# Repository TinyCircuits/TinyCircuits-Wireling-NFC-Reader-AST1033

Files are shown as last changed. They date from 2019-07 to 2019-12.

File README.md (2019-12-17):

# TinyCircuits Wireling NFC Reader
# AST1033 Rev1

The design files are located under design_files/ for the TinyCircuits AST1033 Rev 1 PCB. This is a Wireling board which features the MFRC522 RFID Reader and is designed to communicate with ISO/IEC 14443 A/MIFARE cards and transponders.

Format is in Cadsoft Eagle format - Eagle version 6.2 was used for the original design.

For more infomation on this, check out the product page at TinyCircuits.com

# License:

Design by TinyCircuits.
All design files are released under the Creative Commons Attribution Share-Alike 3.0 License, see the following link for details: http://creativecommons.org/licenses/by-sa/3.0

All text above must be included in any redistribution or derived design

This project uses designs and concepts developed as part of the Arduino project and the LilyPad project.  The TinyCircuits design files themselves (schematics, PCB and libraries) are not directly derived from these works' design files and have been created new, however the concepts and basic architecture behind the TinyDuino and TinyLily products are derived and we thank the hard work of the organizations below for their contributions to open-source hardware:
  
Original Arduino Uno Design by Team Arduino

LilyPad Arduino Design by Leah Buechley and Sparkfun Electronics

Please support the open-source hardware community

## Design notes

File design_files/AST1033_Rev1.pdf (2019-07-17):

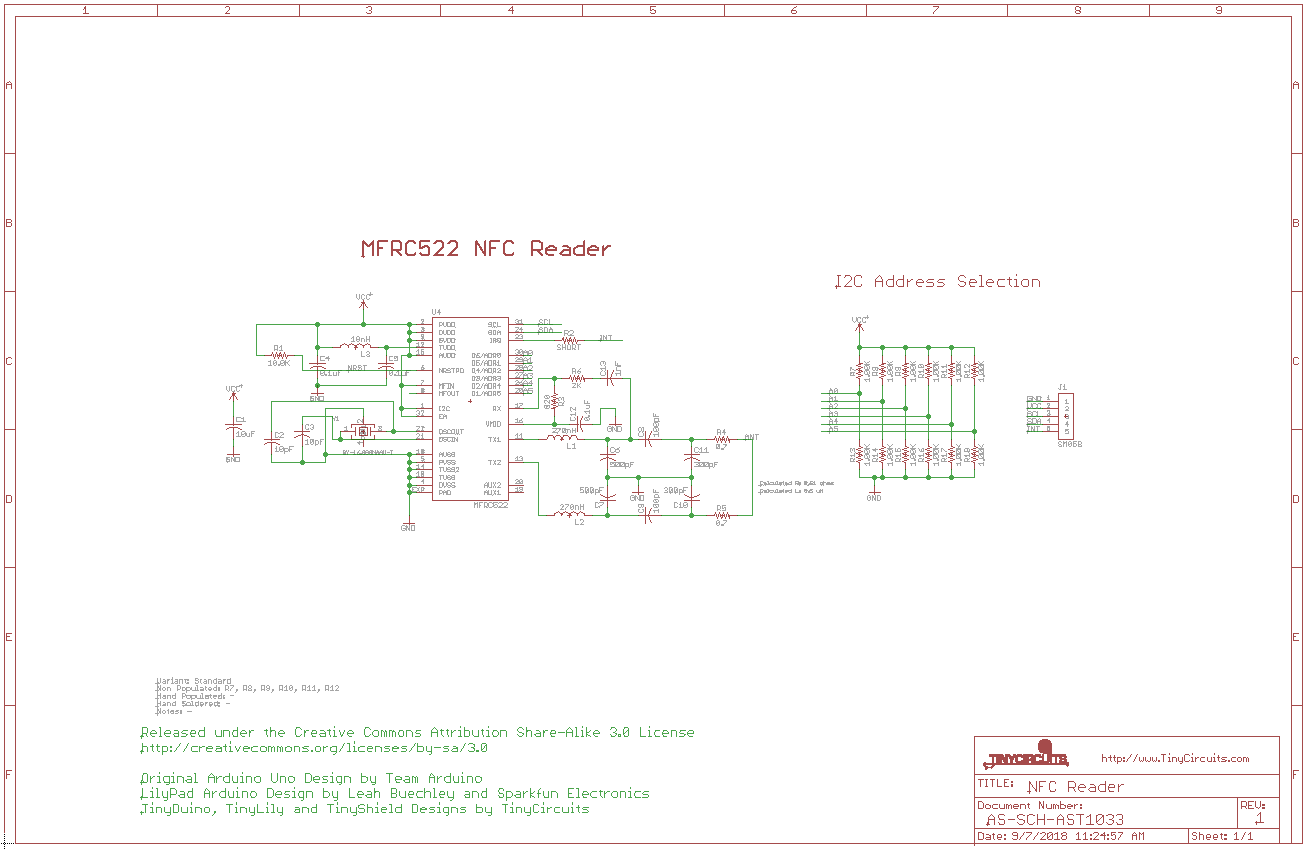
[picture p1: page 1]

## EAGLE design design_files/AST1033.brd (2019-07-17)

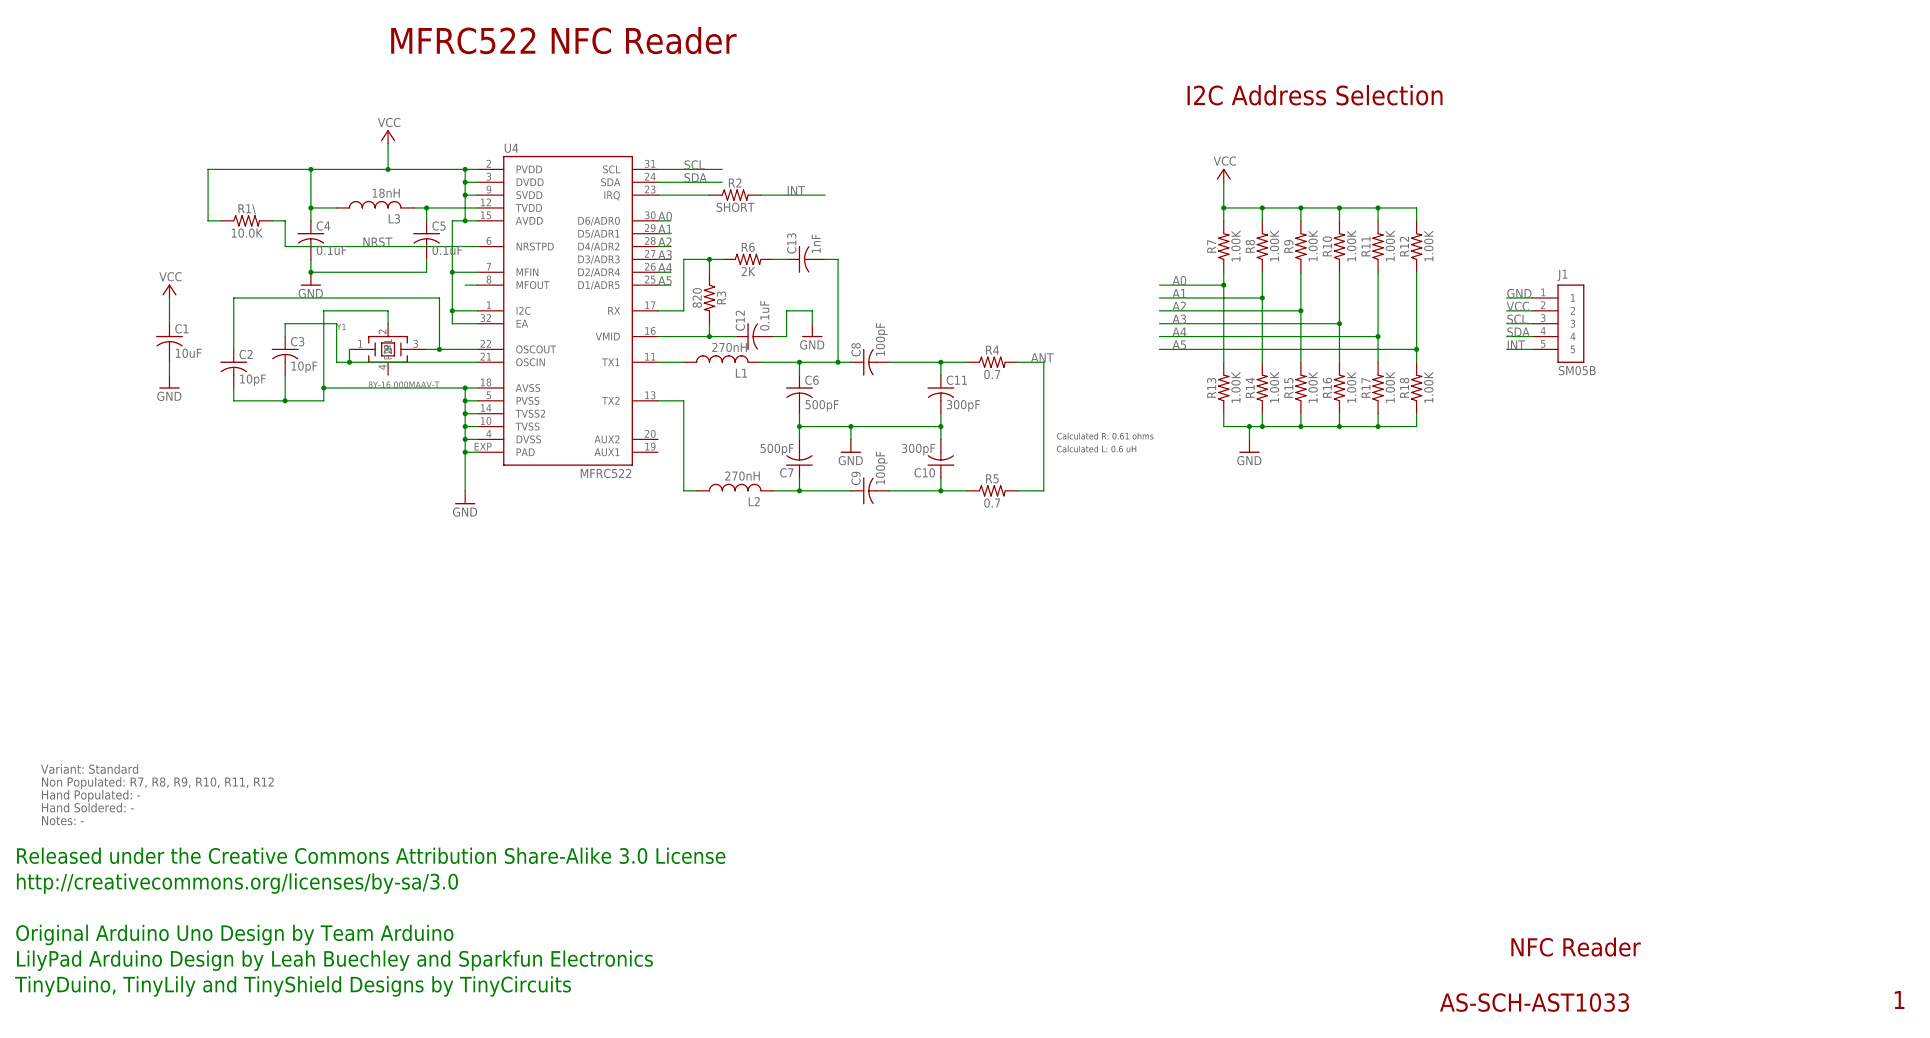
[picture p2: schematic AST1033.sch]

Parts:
C1: 10uF; C0603; PARTNO AS-ITM-00002
C2, C3: 10pF; C0402
C4, C5, C12: 0.1uF; C0402; PARTNO AS-ITM-00008
C6, C7: 500pF; 0402; PARTNO AS-ITM-00148
C8, C9: 100pF; 0402; PARTNO AS-ITM-00148
C10, C11: 300pF; C0402; PARTNO AS-ITM-00008
C13: 1nF; C0402; PARTNO AS-ITM-00008
J1: SM05B; JST_SH_5X1
L1, L2: 270nH; C0402; PARTNO AS-ITM-00250
L3: 18nH; C0402
R1\: 10.0K; 0402
R2: SHORT; 0402_SHORT
R3: 820; 0402; PARTNO AS-ITM-00076
R4, R5: 0.7; 0402
R6: 2K; 0402; PARTNO AS-ITM-00315
R7, R8, R9, R10, R11, R12, R13, R14, R15, R16, R17, R18: 1.00K; 0402
U4: MFRC522; ATMEL_QFN32
Y1: 8Y-16.000MAAV-T; ABM11

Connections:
A0: R7.1, R13.2, U4.30 (D6/ADR0)
A1: R8.1, R14.2, U4.29 (D5/ADR1)
A2: R9.1, R15.2, U4.28 (D4/ADR2)
A3: R10.1, R16.2, U4.27 (D3/ADR3)
A4: R11.1, R17.2, U4.26 (D2/ADR4)
A5: R12.1, R18.2, U4.25 (D1/ADR5)
ANT: R4.2, R5.2
GND: C1.2, C2.2, C3.2, C4.2, C5.2, C6.2, C7.2, C10.2, C11.2, C12.2, J1.1, R13.1, R14.1, R15.1, R16.1, R17.1, R18.1, U4.4 (DVSS), U4.5 (PVSS), U4.10 (TVSS), U4.14 (TVSS2), U4.18 (AVSS), U4.EXP (PAD), Y1.2
INT: J1.5, R2.2
unnamed: R2.1, U4.23 (IRQ)
unnamed: L1.1, U4.11 (TX1)
unnamed: L2.1, U4.13 (TX2)
unnamed: C6.1, C8.1, C13.2, L1.2
unnamed: R3.1, R6.1, U4.17 (RX)
unnamed: C7.1, C9.1, L2.2
unnamed: C2.1, U4.22 (OSCOUT), Y1.3 (2)
unnamed: C3.1, U4.21 (OSCIN), Y1.1
unnamed: C9.2, C10.1, R5.1
unnamed: C12.1, R3.2, U4.16 (VMID)
unnamed: C8.2, C11.1, R4.1
unnamed: C5.1, L3.2, U4.12 (TVDD)
unnamed: C13.1, R6.2
NRST: R1\.2, U4.6 (NRSTPD)
SCL: J1.3, U4.31 (SCL)
SDA: J1.4, U4.24 (SDA)
VCC: C1.1, C4.1, J1.2, L3.1, R1\.1, R7.2, R8.2, R9.2, R10.2, R11.2, R12.2, U4.1 (I2C), U4.2 (PVDD), U4.3 (DVDD), U4.7 (MFIN), U4.9 (SVDD), U4.15 (AVDD), U4.32 (EA)

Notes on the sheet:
NFC Reader
AS-SCH-AST1033
Released under the Creative Commons Attribution Share-Alike 3.0 License
http://creativecommons.org/licenses/by-sa/3.0
LilyPad Arduino Design by Leah Buechley and Sparkfun Electronics
TinyDuino, TinyLily and TinyShield Designs by TinyCircuits
Original Arduino Uno Design by Team Arduino
Calculated L: 0.6 uH
Calculated R: 0.61 ohms
I2C Address Selection
MFRC522 NFC Reader
Non Populated: R7, R8, R9, R10, R11, R12
Hand Populated: -
Hand Soldered: -
Variant: Standard
Notes: -

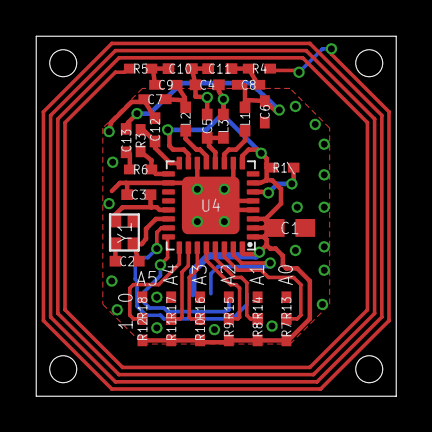
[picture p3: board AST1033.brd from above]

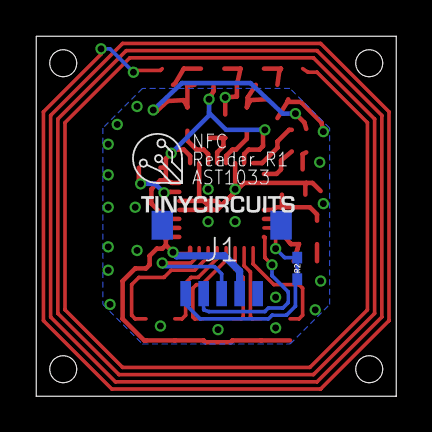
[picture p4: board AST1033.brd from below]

Board: 2 copper layers, 20.0 x 20.0 mm, 38 parts (2 on the bottom side), 26 nets.

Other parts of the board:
U$1: DOCFIELD-TINYCIRCUITS-PCB
